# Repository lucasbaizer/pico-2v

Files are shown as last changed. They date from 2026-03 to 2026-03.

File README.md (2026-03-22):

# Pico 2V

Pico 2V is an [RP2350](https://www.raspberrypi.com/products/rp2350) development board that is (mostly) pin-compatible with the official [Raspberry Pi Pico 2](https://www.raspberrypi.com/products/raspberry-pi-pico-2) board, but with some additional features and changes:

* Switchable 3.3V/1.8V GPIOs: the official Pico 2 only supports running at 3.3V. Pico 2V has a jumper that lets you select between 3.3V and 1.8V.
* QSPI breakout: the official Pico 2 has an RP2350A as the chip, with on-board flash wired to the RP2350A's QSPI interface. Pico 2V has on RP2354A instead, which has 2MiB on-chip flash. As such, the RP2354A's QSPI interface on Pico 2V is broken out into two headers that can fit an [SOIC-8 breakout board](https://www.amazon.com/dp/B0DQKZG7TH) or be wired to some part of your breadboard. This allows you to write firmware that can communicate with QSPI flash using all 4 data lanes.
* On-board reset button.
* Powered-on indicator LED.
* USB-C receptacle instead of the Micro-B receptacle used on the official Pico 2.
* [10-pin Cortex Debug](https://developer.arm.com/documentation/101416/0100/Hardware-Description/Target-Interfaces/Cortex-Debug--10-pin-) connector instead of the [Raspberry Pi 3-pin Debug](https://pip-assets.raspberrypi.com/categories/885-raspberry-pi-debug-probe/documents/RP-008189-DS-1-debug-connector-specification.pdf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) connector used on the official Pico 2.

## Board Rendering and Pinout

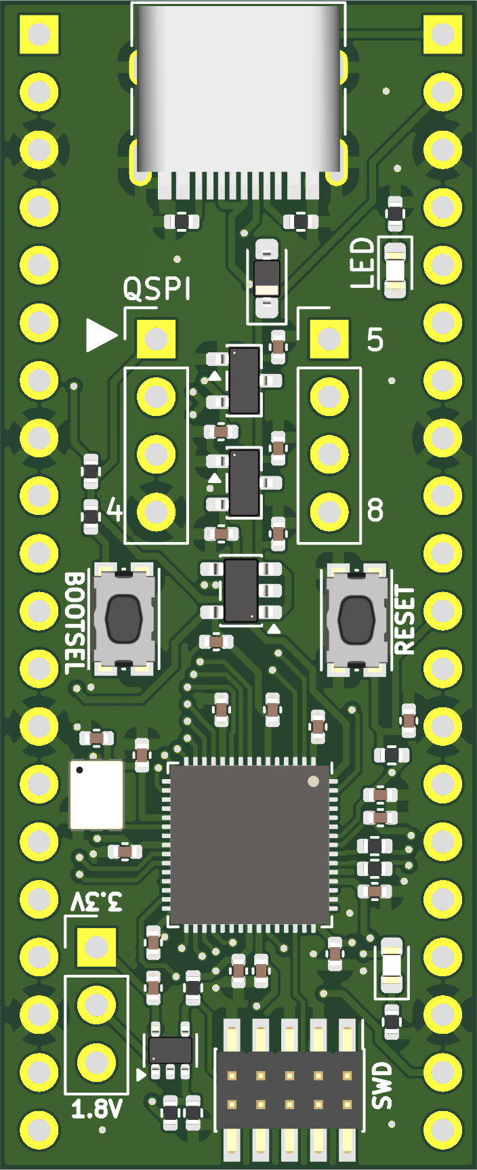
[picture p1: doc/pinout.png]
Pico 2V Pinout


* The GPIO pin headers are pin-compatible with [the official Pico 2](https://www.raspberrypi.com/documentation/microcontrollers/images/pico-2-r4-pinout.svg), and the dimensions of Pico 2V are the same as the official Pico 2, so you can easily swap out an existing Pico 2 on your breadboard for a Pico 2V. However, note that the `3V3(OUT)` pin is actually the output of the selected voltage, so it is instead a `VDD(OUT)` pin, which is only powered when a jumper is fitted to the voltage selector header. Additionally, the `3V3_EN` pin is left floating on Pico 2V.
* GPIO29 (which is not broken out/usable on the official Pico 2) is wired to an on-board voltage comparator, so you can detect from your firmware whether the RP2354A is operating at 3.3V or 1.8V by reading the value of GPIO29 (GPIO29 logic level high indicates 3.3V, logic level low indicates 1.8V). 
* The user LED is connected to GPIO25, just like on the official Pico 2.
* Pressing the `RESET` button will tie the `RUN` pin to ground.
* The QSPI pinout is as follows:
  * Pin 1: `SS` (note that pressing the `BOOTSEL` button will tie this to ground, even after the bootrom exits -- this is a fundamental constraint of how the RP235x bootrom works).
  * Pin 2: `SD1`/`MISO`
  * Pin 3: `SD2`
  * Pin 4: `GND`
  * Pin 5: `VDD` (voltage determined by voltage selection jumper)
  * Pin 6: `SD3`
  * Pin 7: `SCLK`
  * Pin 8: `SD0`/`MOSI`
  * Note that the pin numbering convention here is different from the standard SOIC-8 pin numbering convention. This is a bug with the labeling on the PCB (the '5' and '8' markers should be swapped on the PCB) that will be fixed in rev 1. However, the positions of the pins themselves does match the SOIC-8 layout; the issue is simply in the labeling of the numbers on the PCB.

## How can I buy a Pico 2V?

Fabrication exports are in the `fab/rev0` directory. I had the board produced by [JLCPCB](https://jlcpcb.com). To have JLCPCB produce some boards for you to have, zip all the files in the `fab/rev0` directory and provide the ZIP file to JLCPCB. I used Lead-Free HASL as the surface finish and a PCB thickness of 1mm. If you want them to assembly the components onto the board as well, provide them the BOM and CPL files in `fab/rev0/smt/pico-2v-bom.xls` and `fab/rev0/smt/pico-2v-all-pos.csv` respectively. Note that the GPIO and QSPI headers are not included in the BOM file, but the voltage selection header is; you can select or remove these as you desire.

## Goals for Future Revisions

* Swap the '5' and '8' markers on the QSPI breakout pins.
* Separate voltage selection jumper for QSPI.
* Two more on-board LEDs (since GPIOs 23 and 24 were left unused in rev 0).

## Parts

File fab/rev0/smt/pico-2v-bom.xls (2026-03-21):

Comment | Designator | Footprint | JLCPCB Part #
4.7uF | C1 | C_0402_1005Metric | C23733
10uF | C21 | C_0402_1005Metric | C15525
1uF | C17,C16,C14,C13,C19,C15 | C_0402_1005Metric | C52923
1k | R2,R9 | R_0402_1005Metric | C11702
UK-B0273-SP25Y | SW2,SW1 | SW_Push_1P1T_NO_CK_KMR2 | C99271
BS5817WS | D1 | D_SOD-323_HandSoldering | C122854
MCP1703T-1802E/CB | U3 | SOT-23 | C556901
TLV71311PDBVR | U4 | SOT-23-5 | C205964
LMV331 | U5 | SOT-353_SC-70-5 | C151353
5.1K | R8,R7 | R_0402_1005Metric | C25905
470R | R12,R5 | R_0402_1005Metric | C25117
Conn_02x05_Odd_Even | J7 | PinHeader_2x05_P1.27mm_Vertical_SMD | C41376037
MCP1703T-3302E/CB | U2 | SOT-23 | C53352
RP2354A | U1 | RP2350A-QFN-60-1EP_7x7_P0.4mm_EP3.4x3.4mm_ThermalVias | C41378174
VOLTSEL | J2 | PinHeader_1x03_P2.54mm_Vertical | C49257
0.1uF | C11,C5,C7,C4,C12,C6,C2,C3,C10,C9,C18,C8,C20 | C_0402_1005Metric | C1525
RED | D3,D2 | LED_0603_1608Metric | C205445
ECS-3225MV-120-BN-TR3 | Y1 | ECS-3225MV-120-BN-TR3 | C17560642
10k | R6,R10,R1,R11 | R_0402_1005Metric | C25744
USB_C_Receptacle_USB2.0_16P | J1 | USB_C_Receptacle_HRO_TYPE-C-31-M-12 | C165948
27 | R4,R3 | R_0402_1005Metric | C25100

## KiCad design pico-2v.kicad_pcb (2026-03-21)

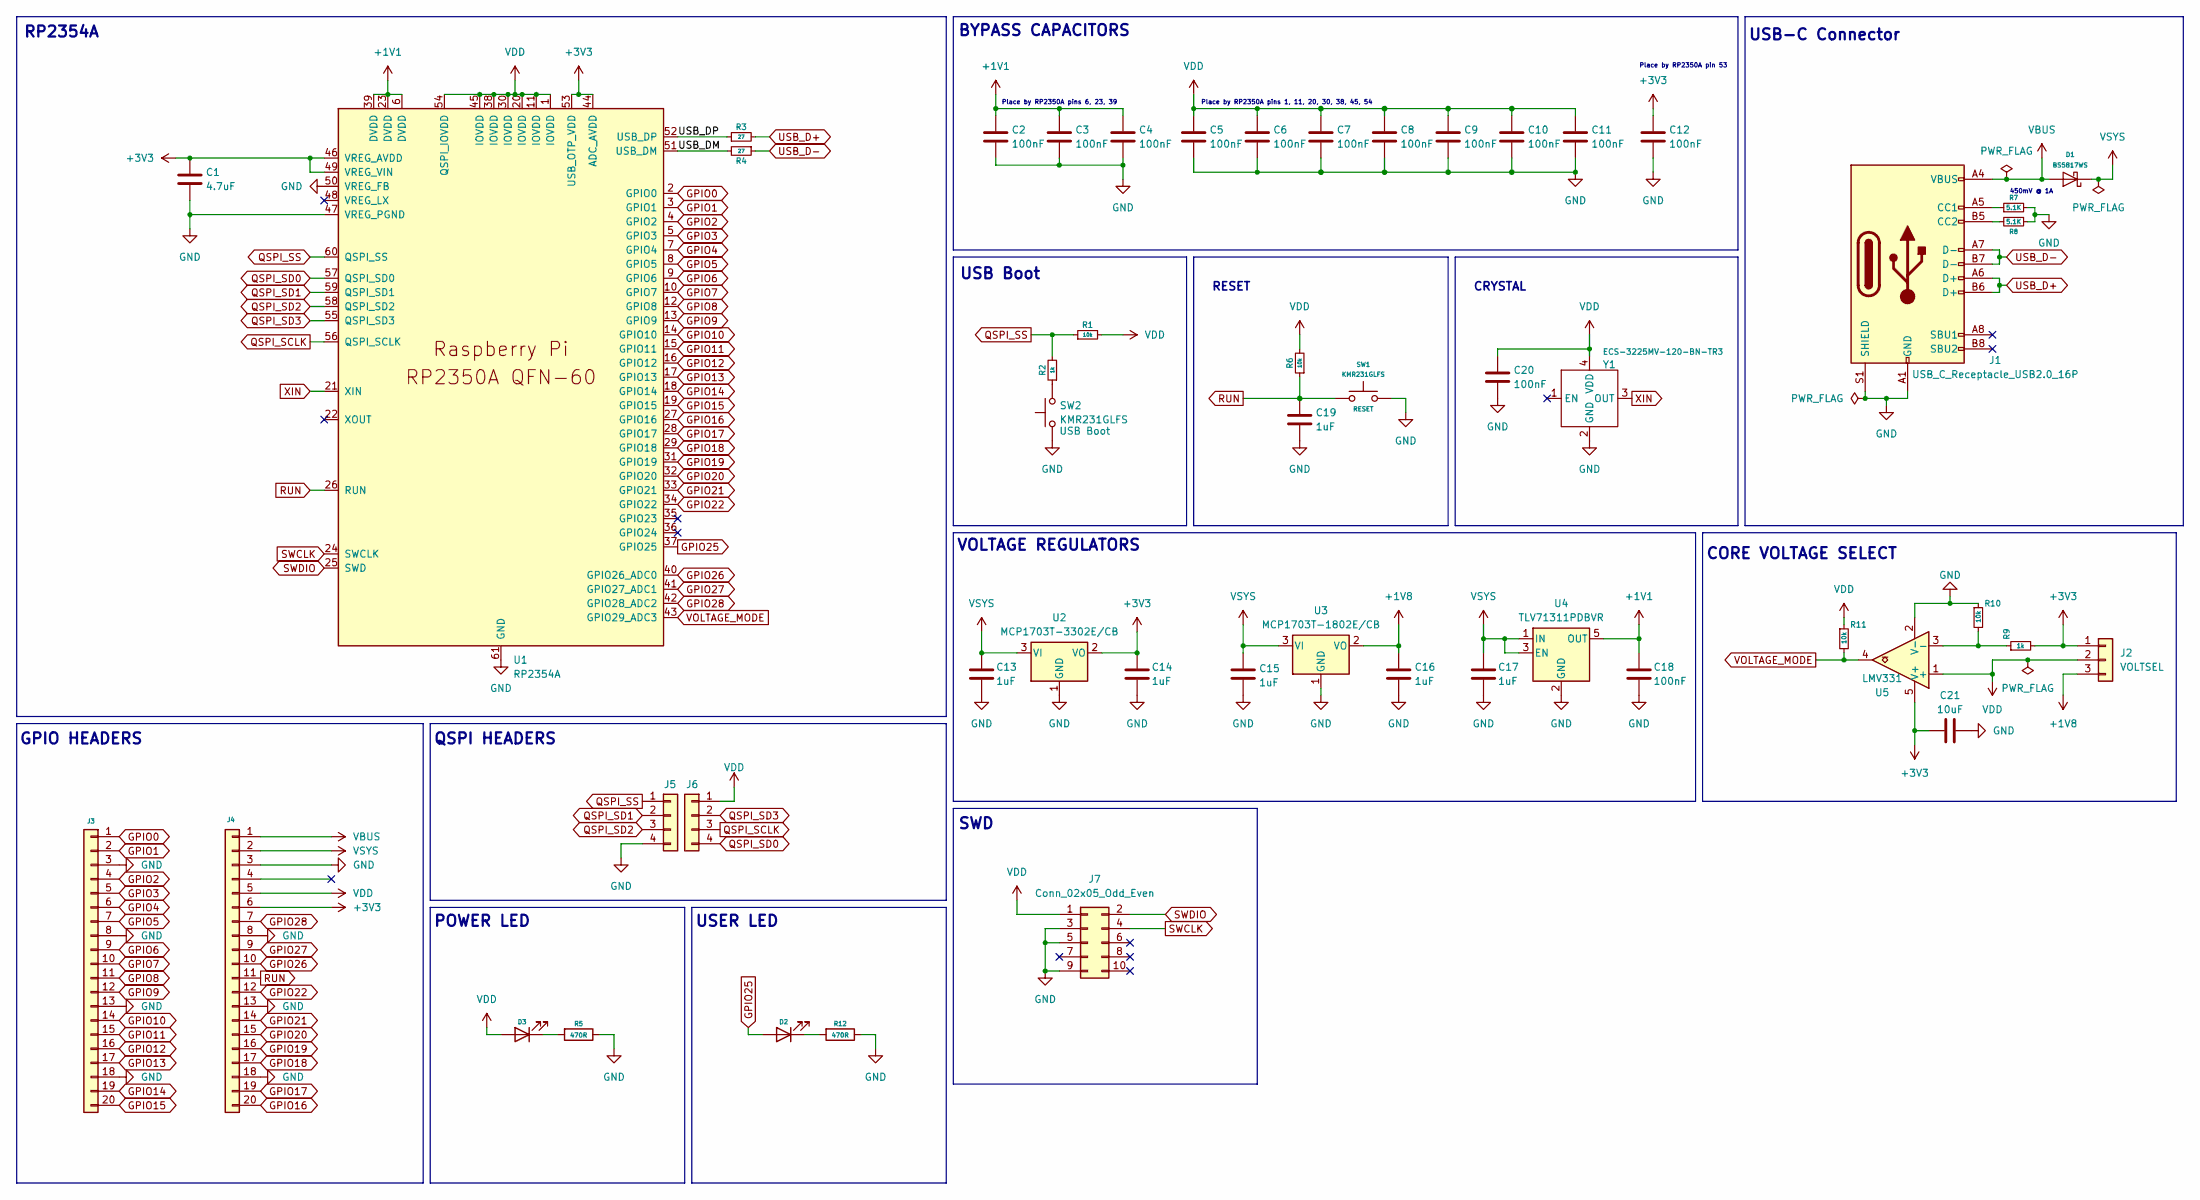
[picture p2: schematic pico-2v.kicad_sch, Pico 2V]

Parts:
C1: 4.7uF; C_0402_1005Metric
C2, C3, C4, C5, C6, C7, C8, C9, C10, C11, C12, C18, C20: 100nF; C_0402_1005Metric
C13, C14, C15, C16, C17, C19: 1uF; C_0402_1005Metric
C21: 10uF; C_0402_1005Metric
D1: BS5817WS; D_SOD-323_HandSoldering; MPN B5817WS
D2, D3: RED; LED_0603_1608Metric; MPN 19-21SURC/S530-A2/TR8
J1: USB_C_Receptacle_USB2.0_16P; USB_C_Receptacle_HRO_TYPE-C-31-M-12
J2: VOLTSEL; PinHeader_1x03_P2.54mm_Vertical
J3: Header-1; PinHeader_1x20_P2.54mm_Vertical; MPN DNP
J4: Header-2; PinHeader_1x20_P2.54mm_Vertical; MPN DNP
J5, J6: Conn_01x04; PinHeader_1x04_P2.54mm_Vertical
J7: Conn_02x05_Odd_Even; PinHeader_2x05_P1.27mm_Vertical_SMD
R1, R6, R10, R11: 10k; R_0402_1005Metric
R2, R9: 1k; R_0402_1005Metric
R3, R4: 27; R_0402_1005Metric
R5, R12: 470R; R_0402_1005Metric; MPN WR04X4700FTL
R7, R8: 5.1K; R_0402_1005Metric; MPN WR04X5101FTL
SW1: KMR231GLFS; SW_Push_1P1T_NO_CK_KMR2; MPN UK-B0273-SP25Y
SW2: KMR231GLFS; SW_Push_1P1T_NO_CK_KMR2
U1: RP2354A; RP2350A-QFN-60-1EP_7x7_P0.4mm_EP3.4x3.4mm_ThermalVias
U2: MCP1703T-3302E/CB; SOT-23
U3: MCP1703T-1802E/CB; SOT-23
U4: TLV71311PDBVR; SOT-23-5
U5: LMV331; SOT-353_SC-70-5
Y1: ECS-3225MV-120-BN-TR3

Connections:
+1V1: C2.1, C3.1, C4.1, C18.1, U1.6 (DVDD), U1.23 (DVDD), U1.39 (DVDD), U4.5 (OUT)
+1V8: C16.1, J2.3, U3.2 (VO)
+3V3: C1.1, C12.1, C14.1, C21.1, J2.1, J4.6, R9.2, U1.44 (ADC_AVDD), U1.46 (VREG_AVDD), U1.49 (VREG_VIN), U1.53 (USB_OTP_VDD), U2.2 (VO), U5.5 (V+)
/USB_DM: R4.2, U1.51 (USB_DM)
/USB_DP: R3.1, U1.52 (USB_DP)
GND: C1.2, C2.2, C3.2, C4.2, C5.2, C6.2, C7.2, C8.2, C9.2, C10.2, C11.2, C12.2, C13.2, C14.2, C15.2, C16.2, C17.2, C18.2, C19.2, C20.2, C21.2, J1.A1 (GND), J1.A12 (GND), J1.B1 (GND), J1.B12 (GND), J1.S1 (SHIELD), J3.3, J3.8, J3.13, J3.18, J4.3, J4.8, J4.13, J4.18, J5.4, J7.3, J7.5, J7.9, R5.1, R7.2, R8.1, R10.1, R12.1, SW1.2, SW2.1, U1.47 (VREG_PGND), U1.50 (VREG_FB), U1.61 (GND), U2.1 (GND), U3.1 (GND), U4.2 (GND), U5.2 (V-), Y1.2 (GND)
GPIO0: J3.1, U1.2 (GPIO0)
GPIO1: J3.2, U1.3 (GPIO1)
GPIO2: J3.4, U1.4 (GPIO2)
GPIO3: J3.5, U1.5 (GPIO3)
GPIO4: J3.6, U1.7 (GPIO4)
GPIO5: J3.7, U1.8 (GPIO5)
GPIO6: J3.9, U1.9 (GPIO6)
GPIO7: J3.10, U1.10 (GPIO7)
GPIO8: J3.11, U1.12 (GPIO8)
GPIO9: J3.12, U1.13 (GPIO9)
GPIO10: J3.14, U1.14 (GPIO10)
GPIO11: J3.15, U1.15 (GPIO11)
GPIO12: J3.16, U1.16 (GPIO12)
GPIO13: J3.17, U1.17 (GPIO13)
GPIO14: J3.19, U1.18 (GPIO14)
GPIO15: J3.20, U1.19 (GPIO15)
GPIO16: J4.20, U1.27 (GPIO16)
GPIO17: J4.19, U1.28 (GPIO17)
GPIO18: J4.17, U1.29 (GPIO18)
GPIO19: J4.16, U1.31 (GPIO19)
GPIO20: J4.15, U1.32 (GPIO20)
GPIO21: J4.14, U1.33 (GPIO21)
GPIO22: J4.12, U1.34 (GPIO22)
GPIO25: D2.2 (A), U1.37 (GPIO25)
GPIO26: J4.10, U1.40 (GPIO26_ADC0)
GPIO27: J4.9, U1.41 (GPIO27_ADC1)
GPIO28: J4.7, U1.42 (GPIO28_ADC2)
unnamed: D2.1 (K), R12.2
unnamed: D3.1 (K), R5.2
unnamed: J1.A5 (CC1), R7.1
unnamed: J1.B5 (CC2), R8.2
unnamed: R2.1, SW2.2
unnamed: R9.1, R10.2, U5.3 (-)
QSPI_SCLK: J6.3, U1.56 (QSPI_SCLK)
QSPI_SD0: J6.4, U1.57 (QSPI_SD0)
QSPI_SD1: J5.2, U1.59 (QSPI_SD1)
QSPI_SD2: J5.3, U1.58 (QSPI_SD2)
QSPI_SD3: J6.2, U1.55 (QSPI_SD3)
QSPI_SS: J5.1, R1.1, R2.2, U1.60 (QSPI_SS)
RUN: C19.1, J4.11, R6.1, SW1.1, U1.26 (RUN)
SWCLK: J7.4, U1.24 (SWCLK)
SWDIO: J7.2, U1.25 (SWD)
USB_D+: J1.A6 (D+), J1.B6 (D+), R3.2
USB_D-: J1.A7 (D-), J1.B7 (D-), R4.1
VBUS: D1.2 (A), J1.A4 (VBUS), J1.A9 (VBUS), J1.B4 (VBUS), J1.B9 (VBUS), J4.1
VDD: C5.1, C6.1, C7.1, C8.1, C9.1, C10.1, C11.1, C20.1, D3.2 (A), J2.2, J4.5, J6.1, J7.1, R1.2, R6.2, R11.1, U1.1 (IOVDD), U1.11 (IOVDD), U1.20 (IOVDD), U1.30 (IOVDD), U1.38 (IOVDD), U1.45 (IOVDD), U1.54 (QSPI_IOVDD), U5.1 (+), Y1.4 (VDD)
VOLTAGE_MODE: R11.2, U1.43 (GPIO29_ADC3), U5.4
VSYS: C13.1, C15.1, C17.1, D1.1 (K), J4.2, U2.3 (VI), U3.3 (VI), U4.1 (IN), U4.3 (EN)
XIN: U1.21 (XIN), Y1.3 (OUT)

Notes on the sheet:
USB Boot
RESET
CORE VOLTAGE SELECT
BYPASS CAPACITORS
CRYSTAL
RP2354A
USB-C Connector
Place by RP2350A pin 53
SWD
QSPI HEADERS
Place by RP2350A pins 6, 23, 39
VOLTAGE REGULATORS
450mV @ 1A
Place by RP2350A pins 1, 11, 20, 30, 38, 45, 54
USER LED
GPIO HEADERS
POWER LED

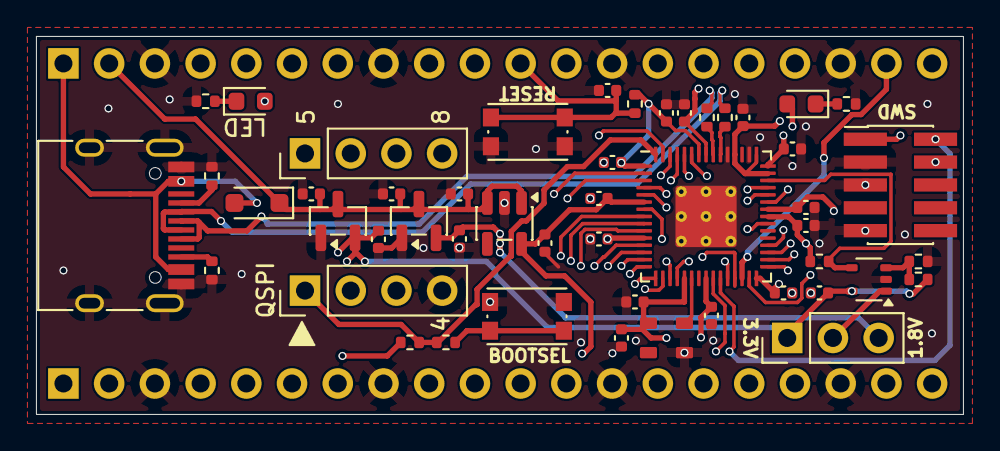
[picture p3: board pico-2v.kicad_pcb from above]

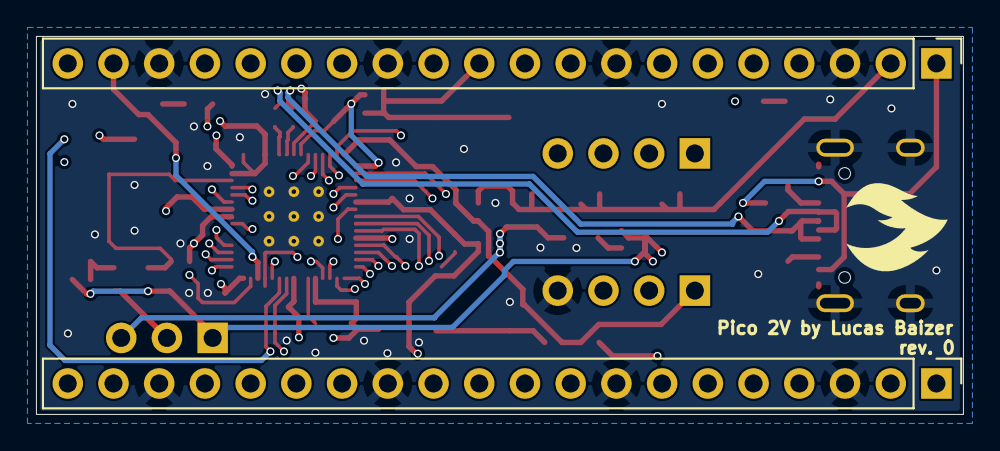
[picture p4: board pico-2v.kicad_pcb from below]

Board: 4 copper layers, 51.5 x 21.0 mm, 51 parts (2 on the bottom side), 55 nets.

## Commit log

2026-03-15 Bug fixes
    [pico-2v.kicad_pcb]
2026-03-21 Various stuff
    [pico-2v.kicad_pcb, pico-2v.kicad_sch]
2026-03-21 Cleanup, documentation
    [pico-2v-B_Cu.gbr, pico-2v-B_Mask.gbr, pico-2v-B_Paste.gbr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]
